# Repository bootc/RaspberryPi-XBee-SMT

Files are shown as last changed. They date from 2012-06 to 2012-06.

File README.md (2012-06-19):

Raspberry Pi XBee ZB SMT Backpack
=================================

This project is for a Raspberry Pi expansion board to accommodate a Digi XBee
ZB SMT board.

The main intention of targeting the ZB SMT is so that the module can be driven
over the SPI bus instead of using the UART. This has several advantages, one of
which is it does not use up the UART so that it can still be used for other
functionality.

The expansion board / backpack is able to host a non-SMT module using the
standard 2mm header. Note that it is impossible to use SPI for modules
connected using this header as the pins are not connected.

Solder jumpers are available to select which SPI chipselect line to use, to
connect the ZB UART to the Raspberry Pi's UART and to connect GPIOs to various
ZB pins (DTR/SLEEP_RQ and INTR).

Submodules
----------

This git repo uses git submodules to pull in SparkFun's Eagle libraries. If you
clone this repo, please run the following commands to pull in the libraries:

```
git submodule init
git submodule update
```

Licensing
---------

<br />This work is licensed under a <a rel="license" href="http://creativecommons.org/licenses/by-sa/2.0/uk/">Creative Commons Attribution-ShareAlike 2.0 UK: England &amp; Wales License</a>.

<a target="_blank" href="http://freedomdefined.org/OSHW">OSHW</a>

&copy;2012 Chris Boot.

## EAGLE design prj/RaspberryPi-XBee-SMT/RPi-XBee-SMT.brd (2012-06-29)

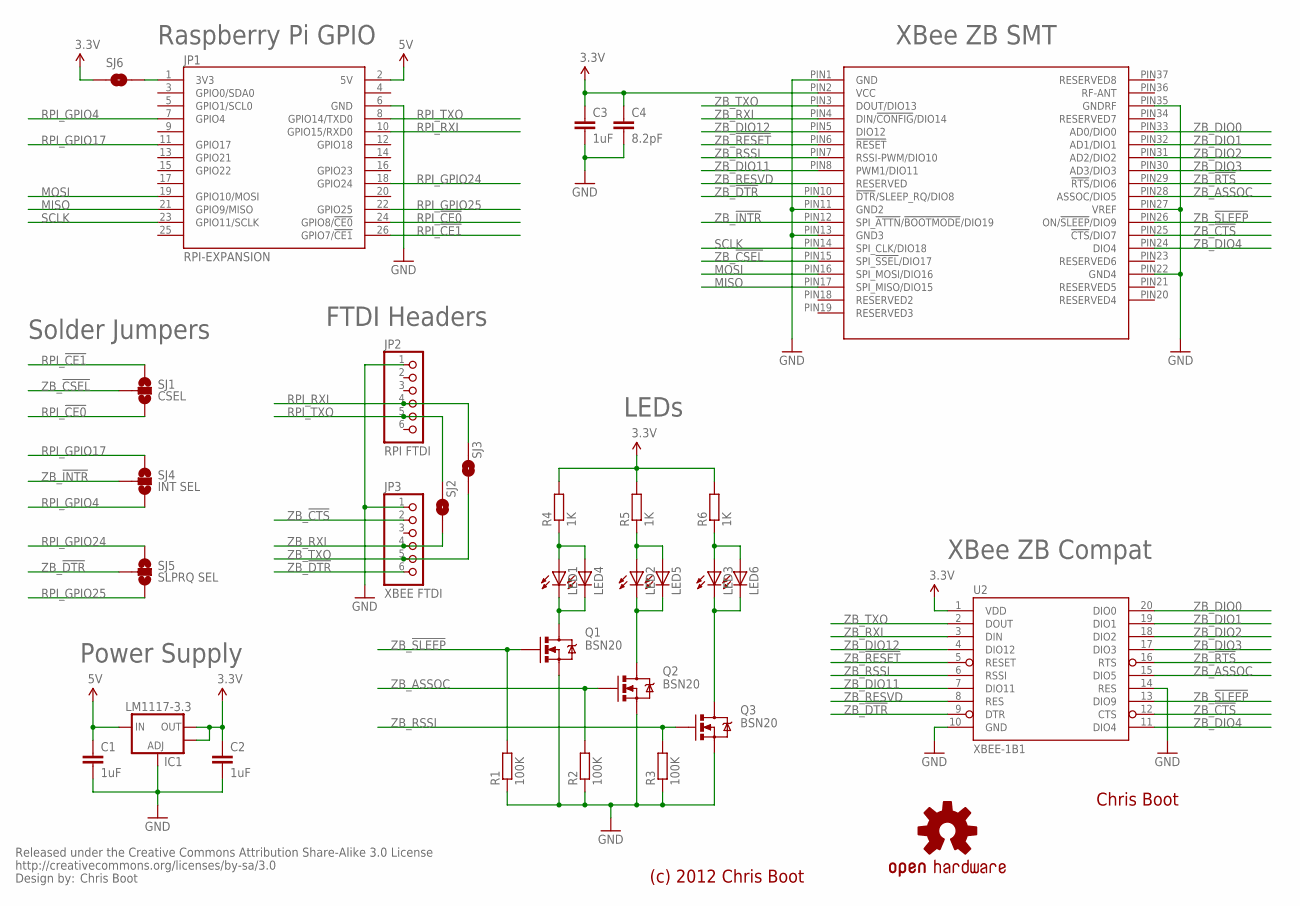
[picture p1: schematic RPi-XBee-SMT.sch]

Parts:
C1, C2, C3: 1uF; C0805
C4: 8.2pF; C0805
IC1: LM1117-3.3; SOT223
JP1: RPI-EXPANSION; 2X13
JP2: RPI FTDI; 1X06
JP3: XBEE FTDI; 1X06
LED1, LED2, LED3: LED-3MM-NO_SILK; LED3MM-NS
LED4, LED5, LED6: LED0603; LED-0603
Q1, Q2, Q3: BSN20; SOT23-3
R1, R2, R3: 100K; R0805
R4, R5, R6: 1K; R0805
SJ1: CSEL; SJ_3
SJ2, SJ3, SJ6: SOLDERJUMPERNO; SJ_2S-NO
SJ4: INT SEL; SJ_3
SJ5: SLPRQ SEL; SJ_3
U1: QUBIQ_XBEE-SMT; QUBIQ_FLAT-RF
U2: XBEE-1B1; XBEE-1
U$3: CREATIVE_COMMONS
U$4: OSHW-LOGOL; OSHW-LOGO-L

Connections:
3.3V: C2.1, C3.1, C4.1, IC1.2 (OUT), IC1.4 (OUT), R4.2, R5.2, R6.2, SJ6.1, U1.PIN2 (VCC), U2.1 (VDD)
5V: C1.1, IC1.3 (IN), JP1.2 (5V)
GND: C1.2, C2.2, C3.2, C4.2, IC1.1 (ADJ), JP1.6 (GND), JP2.1, JP3.1, Q1.2 (S), Q2.2 (S), Q3.2 (S), R1.1, R2.1, R3.1, U1.PIN1 (GND), U1.PIN11 (GND2), U1.PIN13 (GND3), U1.PIN22 (GND4), U1.PIN27 (VREF), U1.PIN35 (GNDRF), U2.10 (GND), U2.14 (RES)
MISO: JP1.21 (GPIO9/MISO), U1.PIN17 (SPI_MISO/DIO15)
MOSI: JP1.19 (GPIO10/MOSI), U1.PIN16 (SPI_MOSI/DIO16)
unnamed: LED1.K (C), LED4.C, Q1.3 (D)
unnamed: LED2.K (C), LED5.C, Q2.3 (D)
unnamed: LED3.K (C), LED6.C, Q3.3 (D)
unnamed: LED1.A, LED4.A, R4.1
unnamed: LED2.A, LED5.A, R5.1
unnamed: LED3.A, LED6.A, R6.1
RPI_3.3V: JP1.1 (3V3), SJ6.2
RPI_!CE0: JP1.24 (GPIO8/!CE0), SJ1.3
RPI_!CE1: JP1.26 (GPIO7/!CE1), SJ1.1
RPI_GPIO4: JP1.7 (GPIO4), SJ4.3
RPI_GPIO17: JP1.11 (GPIO17), SJ4.1
RPI_GPIO24: JP1.18 (GPIO24), SJ5.1
RPI_GPIO25: JP1.22 (GPIO25), SJ5.3
RPI_RXI: JP1.10 (GPIO15/RXD0), JP2.4, SJ3.2
RPI_TXO: JP1.8 (GPIO14/TXD0), JP2.5, SJ2.2
SCLK: JP1.23 (GPIO11/SCLK), U1.PIN14 (SPI_CLK/DIO18)
ZB_!CSEL: SJ1.2, U1.PIN15 (SPI_!SSEL!/DIO17)
ZB_!CTS: JP3.2, U1.PIN25 (!CTS!/DIO7), U2.12 (CTS)
ZB_!DTR: JP3.6, SJ5.2, U1.PIN10 (!DTR!/SLEEP_RQ/DIO8), U2.9 (DTR)
ZB_!INTR: SJ4.2, U1.PIN12 (SPI_!ATTN!/!BOOTMODE!/DIO19)
ZB_!RESET: U1.PIN6 (!RESET), U2.5 (RESET)
ZB_!RTS: U1.PIN29 (!RTS!/DIO6), U2.16 (RTS)
ZB_!SLEEP: Q1.1 (G), R1.2, U1.PIN26 (ON/!SLEEP!/DIO9), U2.13 (DIO9)
ZB_ASSOC: Q2.1 (G), R2.2, U1.PIN28 (ASSOC/DIO5), U2.15 (DIO5)
ZB_DIO0: U1.PIN33 (AD0/DIO0), U2.20 (DIO0)
ZB_DIO1: U1.PIN32 (AD1/DIO1), U2.19 (DIO1)
ZB_DIO2: U1.PIN31 (AD2/DIO2), U2.18 (DIO2)
ZB_DIO3: U1.PIN30 (AD3/DIO3), U2.17 (DIO3)
ZB_DIO4: U1.PIN24 (DIO4), U2.11 (DIO4)
ZB_DIO11: U1.PIN8 (PWM1/DIO11), U2.7 (DIO11)
ZB_DIO12: U1.PIN5 (DIO12), U2.4 (DIO12)
ZB_RESVD: U1.PIN9 (RESERVED), U2.8 (RES)
ZB_RSSI: Q3.1 (G), R3.2, U1.PIN7 (RSSI-PWM/DIO10), U2.6 (RSSI)
ZB_RXI: JP3.4, SJ2.1, U1.PIN4 (DIN/!CONFIG!/DIO14), U2.3 (DIN)
ZB_TXO: JP3.5, SJ3.1, U1.PIN3 (DOUT/DIO13), U2.2 (DOUT)

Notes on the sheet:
Chris Boot
(c) 2012 Chris Boot
XBee ZB SMT
XBee ZB Compat
Raspberry Pi GPIO
LEDs
Power Supply
Solder Jumpers
FTDI Headers

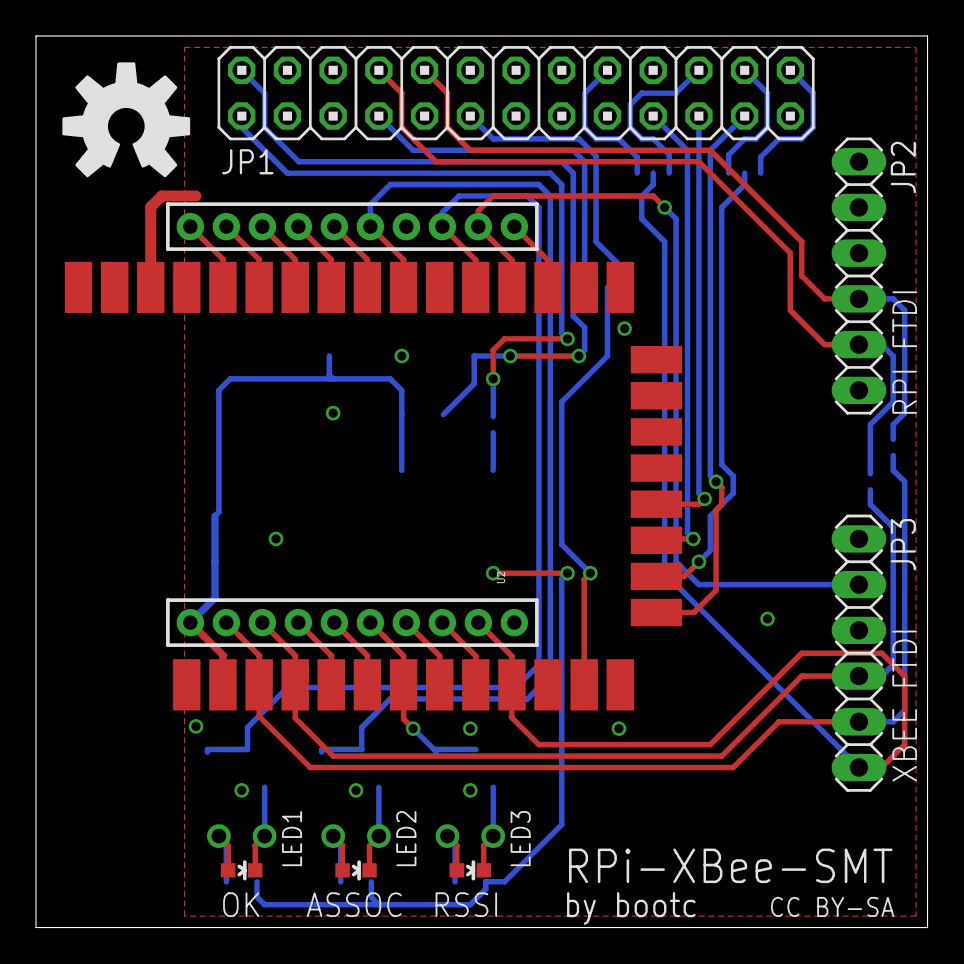
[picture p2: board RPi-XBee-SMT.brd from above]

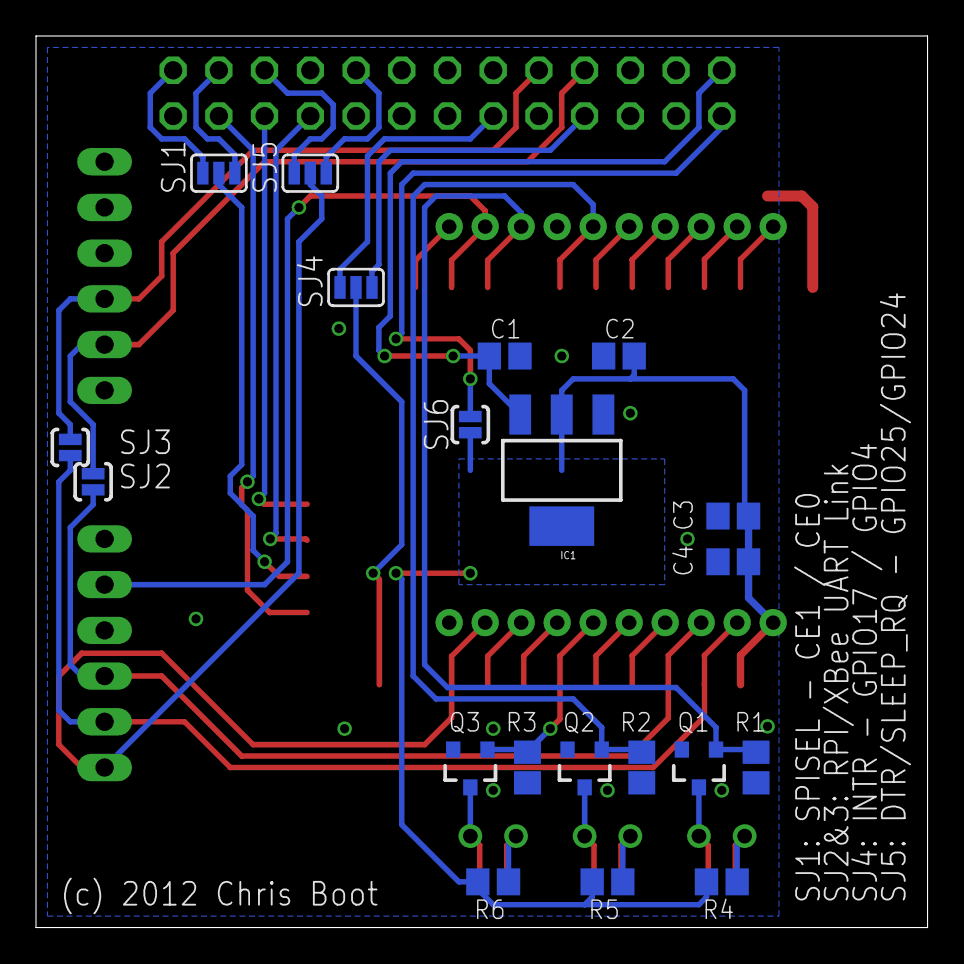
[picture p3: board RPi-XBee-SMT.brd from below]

Board: 2 copper layers, 49.5 x 49.5 mm, 33 parts (20 on the bottom side), 40 nets.

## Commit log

2012-06-19 First public release.
    [RPi-XBee-SMT.brd, RPi-XBee-SMT.sch]
2012-06-19 Move JP1 label back onto the board.
    [RPi-XBee-SMT.brd]
2012-06-20 Add solder jumper to power XBee from RPI 3.3V
    This will allow people to omit the LDO if they would rather power the
    XBee module straight from the Raspberry Pi's 3.3V rail.
    This update also does some minor trace re-routing and moves some text
    around the board a bit.
    [RPi-XBee-SMT.brd, RPi-XBee-SMT.sch]
2012-06-20 Rename proj => prj
    [RPi-XBee-SMT.brd, RPi-XBee-SMT.sch]
2012-06-29 Move the Eagle files into a project directory.
    [RPi-XBee-SMT.brd, RPi-XBee-SMT.sch]
2012-06-29 Fix up some 10mil traces to 12mil
    [RPi-XBee-SMT.brd, RPi-XBee-SMT.sch]

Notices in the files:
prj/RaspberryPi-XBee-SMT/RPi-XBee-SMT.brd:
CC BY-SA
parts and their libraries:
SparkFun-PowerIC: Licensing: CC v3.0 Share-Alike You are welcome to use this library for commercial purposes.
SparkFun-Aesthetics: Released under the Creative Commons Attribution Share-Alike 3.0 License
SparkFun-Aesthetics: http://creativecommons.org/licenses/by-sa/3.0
